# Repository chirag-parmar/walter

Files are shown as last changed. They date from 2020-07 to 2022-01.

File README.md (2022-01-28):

# Walter: The Water Butler

> Proof of concept document can be found [here](docs/POC.md)

### Dependencies: *(Tested on MACOS)*

1. [Download](https://www.nordicsemi.com/Software-and-tools/Software/nRF5-SDK/Download) nRF5 SDK
2. [Download](https://developer.arm.com/tools-and-software/open-source-software/developer-tools/gnu-toolchain/gnu-rm/downloads) ARM GCC toolchain
4. [Download](https://www.nordicsemi.com/Software-and-Tools/Development-Tools/nRF-Command-Line-Tools/Download#infotabs) nRF5x Command Line Tools.
4. Extract nRF5 SDK and rename the extracted folder to `nrf5-sdk`.
5. Extract GCC ARM toolchain and rename the extracted folder to `arm-toolchain`
6. Extract `nRF5x Command Line Tools` TAR file.
    * Navigate inside the nrf ommand line tools folder and install the Jlink package withing it.
    * Navigate inside the nrf ommand line tools folder and install the `nRF5x Command Line Tools` package withing it.
7. Check installations
    * J-Link *(MAC-OS)*: Check if this path exists `/Applications/SEGGER/JLink`
    * nRF5x Command Line Tools: `nrfjprog -v` must output the version.
8. Export Environment variables to specifying SDK folder path and ARM toolchain path.
    * `export SDK_ROOT=<PATH TO nrf5-sdk/ folder>`
    * `export GNU_INSTALL_ROOT=<PATH TO arm-toolchain/bin/ folder>`

> MAC-OS Complications: The system is going to complain that "the developer cannot be verified" for `arm-none-eabi-gcc`, `cc1`, `as`, `collect2`, `ld`, `liblto_plugin.0.so`, `arm-none-eabi-size`, `arm-none-eabi-objcopy`. Click on `Cancel` and then open Security and Privacy settings and click on `Allow Anyway`. These complains are gonna show one after the another.

### Burning the software:
```bash
make flash
```

### TODO:
* [x] [IMPORTANT] Debug NRF52840 - doesn't stop advertising at all
* [x] [IMPORTANT] initialize GPIO only while reading the sensor.
* [x] [IMPORTANT] Debug app: after refresh or after close and restart of app BLE shows connected but not re4ading notifications - most probably it is the BleManager object that has gone out of scope.
* [ ] README Documentation
  * [ ] NRF softdevice and flashing instructions without debugger and with debugger 
* [ ] Statistical and Analytical
  * [ ] function for analysing a day's worth of data and extracting the num. of bottles drank metric
  * [ ] triggers for interacting with the user
  * [ ] Touch sensing
* [ ] Software
  * [ ] Using NRF52840 Dongle.
    * [x] Port Capcitive Sensor library to nRF
    * [x] Define BLE services and characteristics
    * [ ] Finish battery level indication integration (depends on power supply design)
  * [x] App Design
    * [x] POC integration with BLE
    * [x] UI Wire Frame
    * [x] UI Design and Integration with BLE
    * [x] run ble recorded in background
    * [x] save data locally - ~~use firebase~~
      * [x] save device info
      * [x] save readings
      * [x] save calibration values
      * [x] save settings
      * [x] save on change
    * [x] Main screen statistics design
* [ ] Hardware
  * [ ] Sensor fabrication documentation
  * [ ] hardware fabrication documentation
  * [x] ~~Aluminium or Copper Tape electrodes~~ - didn't try but shouldn't be too different
  * [x] ~~3D printed case~~ - Going with no case design. who cares about the case anyway. The board is waterproofed
  * [x] Power supply design
    * [x] Coin Cells/ Super Capacitors - Super capacitor can power only for 6 minutes
      * [x] Investigate if we can use coin cells/super capacitors
      * [x] Calculate the usage time per charge and choose an appropriately sized battery
      * [x] Design necessary circuitry for using coin/cell or supercapcitors
      * [x] Fabricate and Integrate circuitry and battery with nrf52840

### Power Caclulations for Supercapacitor

Current draw - 11uA for 8 s and 3 ma for 2s => ~600uA (average)
Power Consumption at 3.6v = 3.6v * 600uA => 2.16mW

Energy stored in the capacitor = 1/2*C*deltaV*deltaV = 0.5 * 1F * (3.6v- 2v)^2 = 1.28J Joules

Energy = Power * Time => Time = Energy/Power => 1.28J/2.16mW => 592s => ~10minutes

**Decision:** Use CR2032 or better rechargeable CR2032

### Future Ideas:

* [ ] onboarding flow
* [ ] social - share water usage statistics with a friend, challenges etc.
* [ ] better UI

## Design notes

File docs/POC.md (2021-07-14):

# Walter: Proof of Concept

> The proof of concept is done using arduino uno. The .ino files can be found in the `arduino` folder.

## The Science of Walter

The primary design goal of this project is to use a non-intrusive sensor to avoid contamination of potable water. Therefore, we use a DIY capacitance based sensor and to keep it simple we go with parallel plate design. The two plates are made of aluminium foil and are fixed to the outside wall of the bottle. To create a mathematical model let's start with the famous capacitance equation shown below.

parallel_plate_cap

Since the combined dielectric constant would be a function of the height of the water we can simply measure the capacitance and deduce the height of the water. Easy-peazy lemon-squeazy, just that it is not that easy.

The first complexity is that we cannot model it as a parallel plate capacitor. Simply because the plates are not parallel, in other words, the distance between the plates is not constant it varies along the shorter edge of the plate.

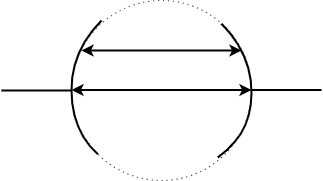
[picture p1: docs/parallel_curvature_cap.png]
parallel_curvature_cap


The second complexity is that the electrical conductivity of water also has a role to play in the increase of capacitance. Potable water even though being "bad" is a conductor (unless you are drinking distilled water). Due to this the water acts like a "bad" conducting metal slab between our capacitor. Due to this the effective capacitor circuit is equivalent to two capacitors connected in series with a high reistance between them. Watch [this](https://www.youtube.com/watch?v=ygADYZEBmtc) video to know why.

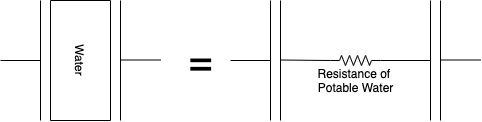
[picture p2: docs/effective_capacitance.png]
effective_capacitance


Therefore, in addition to factoring in a "varying" `d` we would also have to factor in the effect of water as a bad conductor(the electrical conductivity) along with the effect of dielectric constant. One cannot get tangled into the physics of things while playing the role of a hobbyist (one can actually, but one is planning not to. XD). So we just move forward by considering it to be a blackbox and use analytical methods to find the relation between the capacitance and the level of water.

## The Analytics of Walter

#### Quick Setup:
```bash
virtualenv venv
source venv/bin/activate
pip3 install -r requirements.txt
```

#### Collecting Datapoints:

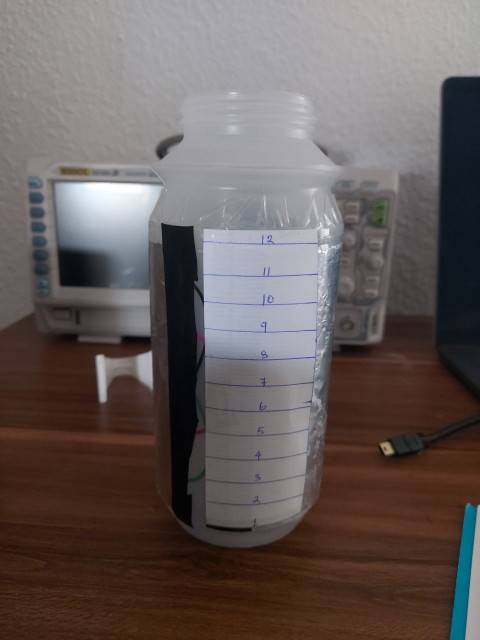
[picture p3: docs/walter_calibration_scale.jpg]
walter_calibration_scale


```bash
python3 scripts/create_dataset.py
```

This python script runs a infinite loop while asking the user two questions in every iteration fo the loop.

1. "Enter number of datapoints to collect(q/Q - quit): " - this is where the user can specify the number of datapoints to be collected or type in `q` or `Q` to quit.
2. "Enter the level of water: " - The water level entered here will be used for all the datapoints that were specified in the question above.

Each datapoint is stored as JSON string as shown below and each dataset is a `List` of datapoints.

```json
{
  "index": 0,
  "val": 742,
  "level": 0,
}
```

* `index` (*self-explanatory*)automatically incremented for every new datapoint.
* `val` represents the sensor value.
* `level` marks the level of water.

This repository has two pre-existing datasets,
1. `linear_filling` - datapoints are collected starting from `level 0` and linearly incrementing thereafter upto `level 13`.
2. `exponential_filling` datapoints are collected starting from `level 0` and exponentially incrementing thereafter upto level 13 i.e. at 0, 1, 2, 4, 8, 13

#### Analyzing the data:

```bash
python3 scripts/statistics.py datasets/<name_of_json_dataset>
```

Linear Filling:
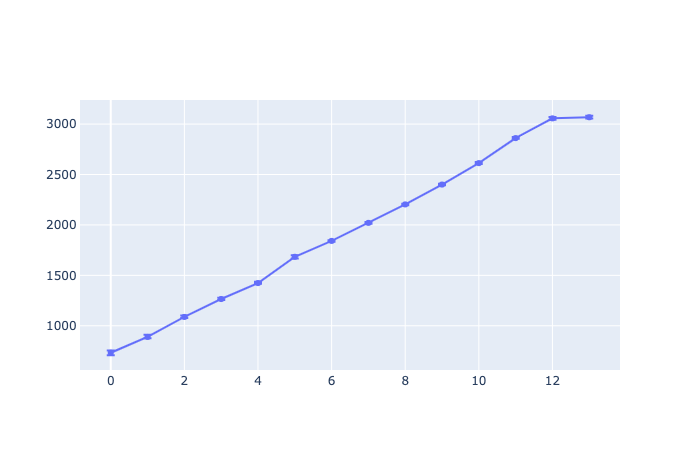
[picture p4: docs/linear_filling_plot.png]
linear_filling_plot

*zoomed in view of `level 6` error bar*
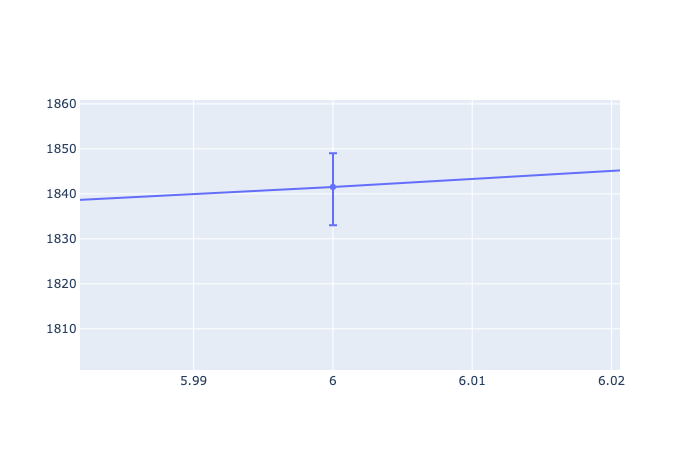
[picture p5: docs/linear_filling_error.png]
linear_filling_error


Exponential Filling:
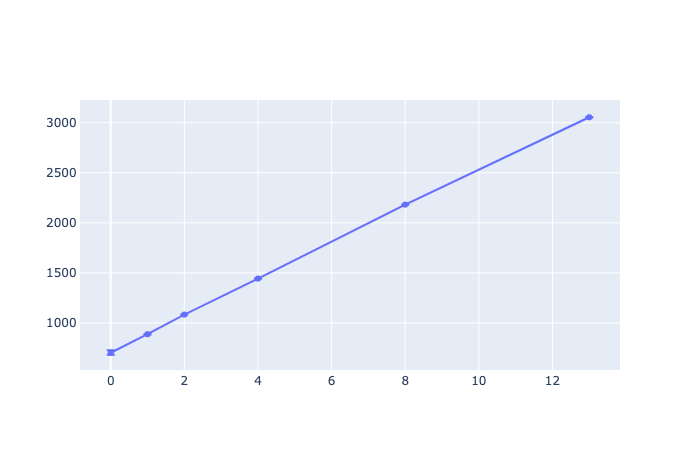
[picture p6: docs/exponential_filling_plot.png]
exponential_filling_plot

*zoomed in view of `level 4` error bar*
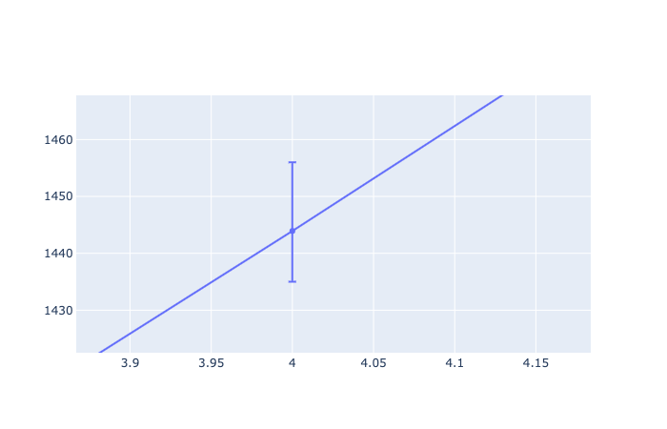
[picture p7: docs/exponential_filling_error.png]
exponential_filling_error


We can deduce the following conclusions of the experiment
1. The sensor value is more or less **linearly** dependent on the level of water.
    * Flattening/breaking of the line after `level 12` of water in the `linear_filling` plot is because level 13 is above the plate area of the capacitor and hence has no or minimal effect on the capacitance.
2. The error in the values is max at +/- 10. This is **super awesome** considering we had to write only a couple of lines of code and solder one resistor to make the sensor.

Further questions to ponder upon:
* Is the linear relationship because of the **uniform** nature of the cylindrical bottle?
* What if the shape of the bottle is not uniform across the cross section of the plates
* Since the relationship is linear can we simply collect two datapoints and compute the line equation? (reaping the benefits of continuity of the realtionship)

## The Touch of Walter

The touch sensing of Walter was an accidental discovery but was not surprising because we are using `CapacitiveSensor` library. This library is majorly used for capacitive `touch` sensing.

So when we open up a up the `serial plotter` provided inside the Arduino IDE and connect Walter via a serial connection we notice that:
1. The sensor value shoots up higher than normal when we touch the bottle.
2. The touch values are higher when the bottle is grabbed tighter.
3. The touch values are higher when the bottle is filled up.

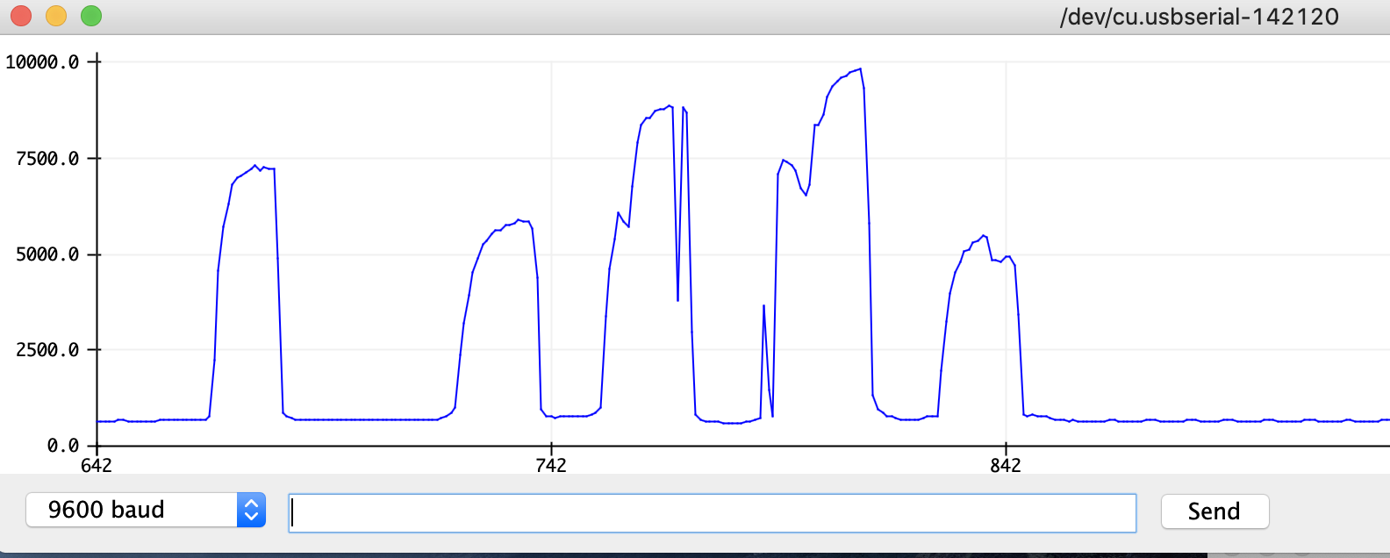
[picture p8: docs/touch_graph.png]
touch_graph


Since the sensor values are *wayyyyyy* higher than normal values we can check for threshold. Whenever the sensor value is greater than this threshold then we can say that the bottle is touched.

For the above graph a practical threshold value would be `5000` since all the peaks cross that mark and our normal maximum value is close to `3000`(full bottle)

#### Circuit Diagram:
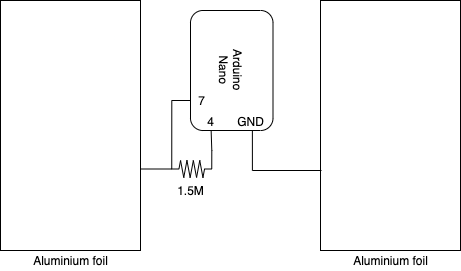
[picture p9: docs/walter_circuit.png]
walter_circuit


## Images
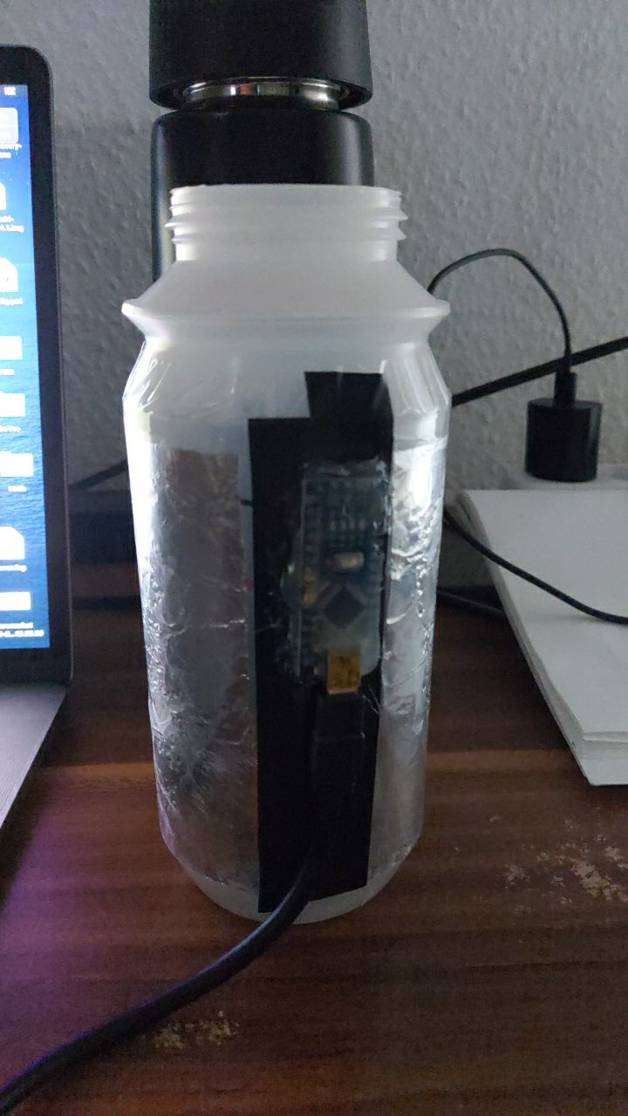
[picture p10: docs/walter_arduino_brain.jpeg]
walter_arduino_brain


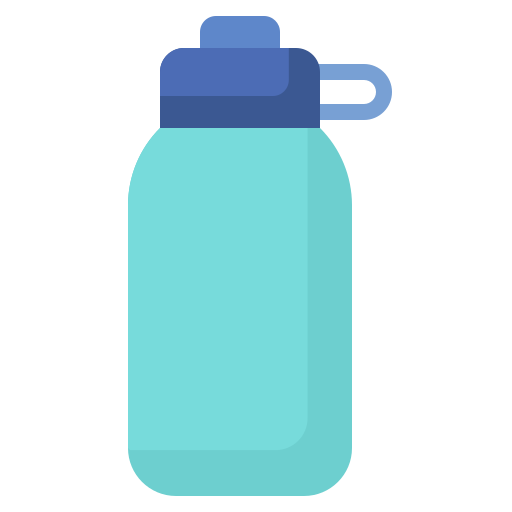
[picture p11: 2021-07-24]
app/Walter/src/resources/water-bottle-blue.png

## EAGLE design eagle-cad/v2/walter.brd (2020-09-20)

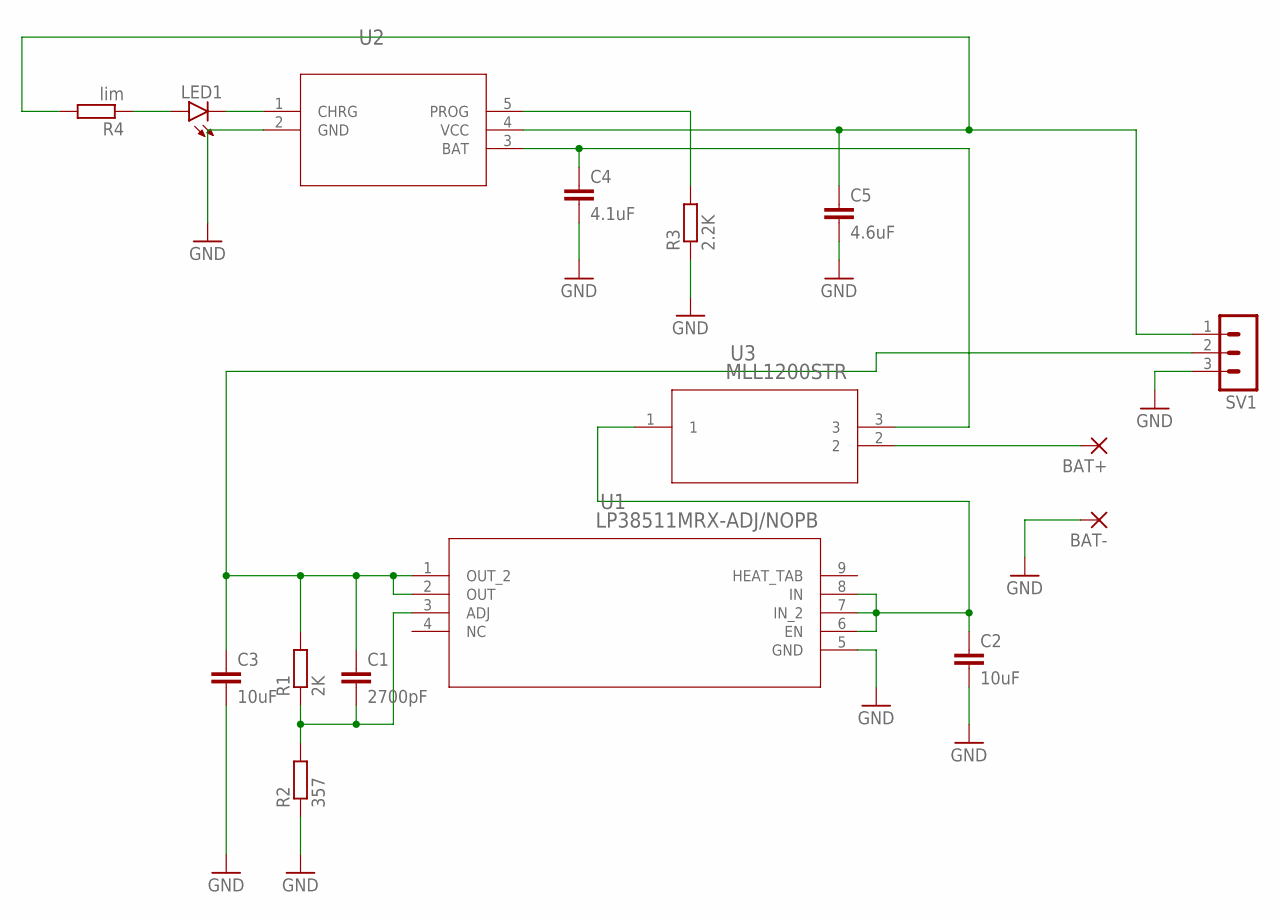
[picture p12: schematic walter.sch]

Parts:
BAT+: 1,6/0,8
BAT-: 1,6/0,8
C1: 2700pF; C0402
C2, C3: 10uF; C0603
C4: 4.1uF; C0603
C5: 4.6uF; C0603
LED1: LEDCHIP-LED0603; CHIP-LED0603
R1: 2K; R0402
R2: 357; R0603
R3: 2.2K; R0603
R4: lim; R0402
SV1: MA03-1
U1: LP38511MRX-ADJ/NOPB; MRA08B_TEX
U2: LTC4054LES5-4.2TRPBF; S_5_ADI
U3: MLL1200STR; SW_MLL1200STR_TEC

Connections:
GND: BAT-.1, C2.2, C3.2, C4.2, C5.2, R2.1, R3.1, SV1.3, U1.5 (GND), U2.2 (GND)
unnamed: C2.1, U1.6 (EN), U1.7 (IN_2), U1.8 (IN), U3.1
unnamed: C4.1, U2.3 (BAT), U3.3
unnamed: C1.1, C3.1, R1.2, SV1.2, U1.1 (OUT_2), U1.2 (OUT)
unnamed: C1.2, R1.1, R2.2, U1.3 (ADJ)
unnamed: BAT+.1, U3.2
unnamed: R3.2, U2.5 (PROG)
unnamed: C5.1, R4.2, SV1.1, U2.4 (VCC)
unnamed: LED1.A, R4.1
unnamed: LED1.C, U2.1 (CHRG)

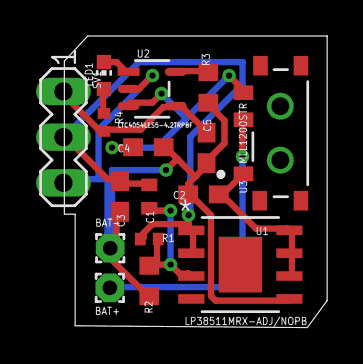
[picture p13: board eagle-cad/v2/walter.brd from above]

Board: 2 copper layers, 14.6 x 16.2 mm, 16 parts (0 on the bottom side), 10 nets.

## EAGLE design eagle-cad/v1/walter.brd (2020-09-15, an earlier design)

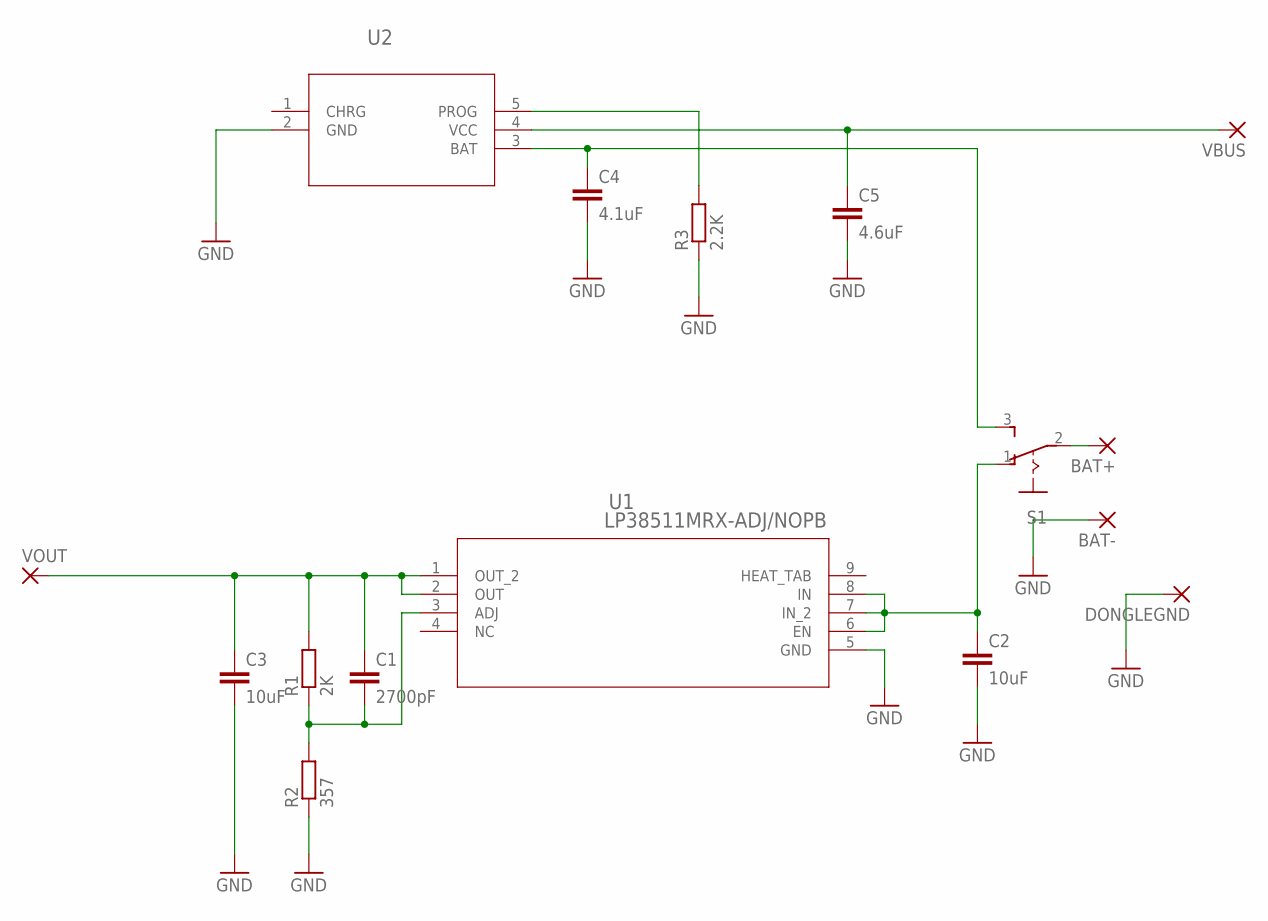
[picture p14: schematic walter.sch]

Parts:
BAT+: 1,6/0,8
BAT-: 1,6/0,8
C1: 2700pF; C0402
C2, C3: 10uF; C0603
C4: 4.1uF; C0603
C5: 4.6uF; C0603
DONGLEGND: 1,6/0,8
R1: 2K; R0402
R2: 357; R0603
R3: 2.2K; R0603
S1: 255SB
U1: LP38511MRX-ADJ/NOPB; MRA08B_TEX
U2: LTC4054LES5-4.2TRPBF; S_5_ADI
VBUS: 1,6/0,8
VOUT: 1,6/0,8

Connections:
GND: BAT-.1, C2.2, C3.2, C4.2, C5.2, DONGLEGND.1, R2.1, R3.1, U1.5 (GND), U2.2 (GND)
unnamed: C2.1, S1.1 (O), U1.6 (EN), U1.7 (IN_2), U1.8 (IN)
unnamed: C4.1, S1.3 (S), U2.3 (BAT)
unnamed: C1.1, C3.1, R1.2, U1.1 (OUT_2), U1.2 (OUT), VOUT.1
unnamed: C1.2, R1.1, R2.2, U1.3 (ADJ)
unnamed: BAT+.1, S1.2
unnamed: R3.2, U2.5 (PROG)
unnamed: C5.1, U2.4 (VCC), VBUS.1

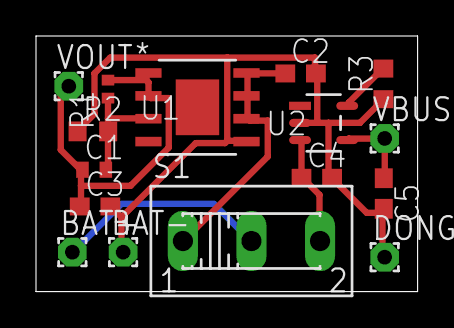
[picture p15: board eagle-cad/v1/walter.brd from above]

Board: 2 copper layers, 21.2 x 14.2 mm, 16 parts (0 on the bottom side), 8 nets.

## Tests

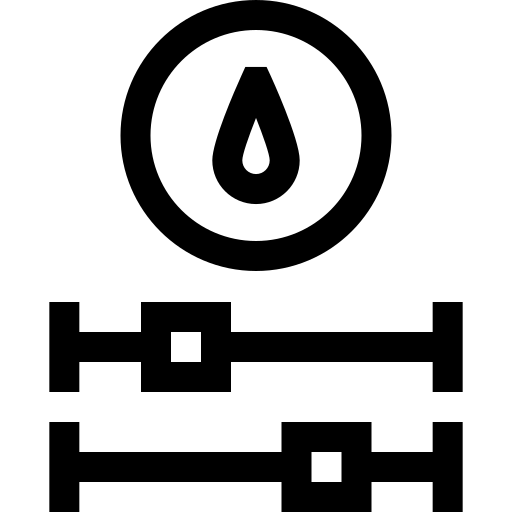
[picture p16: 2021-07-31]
app/Walter/src/resources/calibrate.png

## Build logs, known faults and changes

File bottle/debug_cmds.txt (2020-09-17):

target remote localhost:2331
mon speed 10000
mon flash download=1
load
break main
mon reset 0

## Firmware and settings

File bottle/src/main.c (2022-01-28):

/* Standard Includes */
#include <stdbool.h>
#include <stdint.h>
#include <string.h>

/* SDK Includes */
#include "nordic_common.h"
#include "nrf.h"
#include "app_error.h"
#include "ble.h"
#include "ble_hci.h"
#include "ble_srv_common.h"
#include "ble_advdata.h"
#include "ble_advertising.h"
#include "ble_conn_params.h"
#include "nrf_sdh.h"
#include "nrf_sdh_soc.h"
#include "nrf_sdh_ble.h"
#include "app_timer.h"
#include "fds.h"
#include "peer_manager.h"
#include "peer_manager_handler.h"
#include "bsp_btn_ble.h"
#include "sensorsim.h"
#include "ble_conn_state.h"
#include "nrf_ble_gatt.h"
#include "nrf_ble_lesc.h"
#include "nrf_ble_qwr.h"
#include "nrf_pwr_mgmt.h"
#include "nrf_log.h"
#include "nrf_log_ctrl.h"
#include "nrf_log_default_backends.h"

/* Project Includes */
#include "ble_walter.h"
#include "wlm_sensor.h"

#define DEVICE_NAME                     "Walter"                                /**< Name of device. Will be included in the advertising data. */
#define MANUFACTURER_NAME               "Parmar Industries"                     /**< Manufacturer. Will be passed to Device Information Service. */
#define APP_ADV_INTERVAL                300                                     /**< The advertising interval (in units of 0.625 ms. This value corresponds to 187.5 ms). */

#define APP_ADV_DURATION                3000                                    /**< The advertising duration (180 seconds) in units of 10 milliseconds. */
#define APP_BLE_OBSERVER_PRIO           3                                       /**< Application's BLE observer priority. You shouldn't need to modify this value. */
#define APP_BLE_CONN_CFG_TAG            1                                       /**< A tag identifying the SoftDevice BLE configuration. */

#define MIN_CONN_INTERVAL               MSEC_TO_UNITS(1000, UNIT_1_25_MS)        /**< Minimum acceptable connection interval (4 seconds). */
#define MAX_CONN_INTERVAL               MSEC_TO_UNITS(1000, UNIT_1_25_MS)        /**< Maximum acceptable connection interval (4 second). */
#define SLAVE_LATENCY                   10                                      /**< Slave latency. */
#define CONN_SUP_TIMEOUT                MSEC_TO_UNITS(30000, UNIT_10_MS)         /**< Connection supervisory timeout (4 seconds). */

#define FIRST_CONN_PARAMS_UPDATE_DELAY  APP_TIMER_TICKS(5000)                   /**< Time from initiating event (connect or start of notification) to first time sd_ble_gap_conn_param_update is called (5 seconds). */
#define NEXT_CONN_PARAMS_UPDATE_DELAY   APP_TIMER_TICKS(5000)                  /**< Time between each call to sd_ble_gap_conn_param_update after the first call (30 seconds). */
#define MAX_CONN_PARAMS_UPDATE_COUNT    3                                       /**< Number of attempts before giving up the connection parameter negotiation. */

#define SEC_PARAM_BOND                  1                                       /**< Perform bonding. */
#define SEC_PARAM_MITM                  0                                       /**< Man In The Middle protection not required. */
#define SEC_PARAM_LESC                  0                                       /**< LE Secure Connections not enabled. */
#define SEC_PARAM_KEYPRESS              0                                       /**< Keypress notifications not enabled. */
#define SEC_PARAM_IO_CAPABILITIES       BLE_GAP_IO_CAPS_NONE                    /**< No I/O capabilities. */
#define SEC_PARAM_OOB                   0                                       /**< Out Of Band data not available. */
#define SEC_PARAM_MIN_KEY_SIZE          7                                       /**< Minimum encryption key size. */
#define SEC_PARAM_MAX_KEY_SIZE          16                                      /**< Maximum encryption key size. */

#define DEAD_BEEF                       0xDEADBEEF                              /**< Value used as error code on stack dump, can be used to identify stack location on stack unwind. */

// #define BATTERY_TIMER_INTERVAL          APP_TIMER_TICKS(1000)                   // 1000 ms intervals
#define WLM_TIMER_INTERVAL              APP_TIMER_TICKS(30000)                   // 5 min intervals

//POWER configuration
#define TX_POWER_CONN                   -16
#define TX_POWER_ADV                    -16

NRF_BLE_GATT_DEF(m_gatt);                                                       /**< GATT module instance. */
NRF_BLE_QWR_DEF(m_qwr);                                                         /**< Context for the Queued Write module.*/
BLE_ADVERTISING_DEF(m_advertising);                                             /**< Advertising module instance. */
// APP_TIMER_DEF(m_battery_timer_id);                                              /**< Battery timer. */
APP_TIMER_DEF(m_wlm_timer_id);                                                  /**< water level measurement timer. */

static uint16_t m_conn_handle = BLE_CONN_HANDLE_INVALID;                        /**< Handle of the current connection. */

BLE_WALTER_SERVICE_DEF(m_walter_service);

static ble_uuid_t m_adv_uuids[] =                                               /**< Universally unique service identifiers. */
{
    {WALTER_SERVICE_UUID, BLE_UUID_TYPE_VENDOR_BEGIN}
};


static void advertising_start(bool erase_bonds);


/**@brief Callback function for asserts in the SoftDevice.
 *
 * @details This function will be called in case of an assert in the SoftDevice.
 *
 * @warning This handler is an example only and does not fit a final product. You need to analyze
 *          how your product is supposed to react in case of Assert.
 * @warning On assert from the SoftDevice, the system can only recover on reset.
 *
 * @param[in] line_num   Line number of the failing ASSERT call.
 * @param[in] file_name  File name of the failing ASSERT call.
 */
void assert_nrf_callback(uint16_t line_num, const uint8_t * p_file_name)
{
    app_error_handler(DEAD_BEEF, line_num, p_file_name);
}


/**@brief Function for handling Peer Manager events.
 *
 * @param[in] p_evt  Peer Manager event.
 */
static void pm_evt_handler(pm_evt_t const * p_evt)
{
    pm_handler_on_pm_evt(p_evt);
    pm_handler_flash_clean(p_evt);

    switch (p_evt->evt_id)
    {
        case PM_EVT_PEERS_DELETE_SUCCEEDED:
            advertising_start(false);
            break;

        default:
            break;
    }
}

static void timers_start() {
    ret_code_t err_code;
    err_code = app_timer_start(m_wlm_timer_id, WLM_TIMER_INTERVAL, NULL);
    APP_ERROR_CHECK(err_code);

    // err_code = app_timer_start(m_battery_timer_id, BATTERY_TIMER_INTERVAL, NULL);
    // APP_ERROR_CHECK(err_code);
}

// static void timers_stop() {
//     ret_code_t err_code;
//     err_code = app_timer_stop(m_wlm_timer_id);
//     APP_ERROR_CHECK(err_code);

//     // err_code = app_timer_stop(m_battery_timer_id);
//     // APP_ERROR_CHECK(err_code);
// }

static uint32_t water_level = 0UL;
static void wlm_timer_timeout_handler(void * p_context) {

    ret_code_t err_code;

    //intialize the sensor
    wlm_sensor_init();
    water_level = wlm_sensor_get_reading();
    wlm_sensor_uninit();
    err_code = water_level_update(&m_walter_service, &water_level);

    if ((err_code != NRF_SUCCESS) &&
        (err_code != NRF_ERROR_INVALID_STATE) &&
        (err_code != NRF_ERROR_RESOURCES) &&
        (err_code != NRF_ERROR_BUSY) &&
        (err_code != BLE_ERROR_GATTS_SYS_ATTR_MISSING)
       )
    {
        APP_ERROR_HANDLER(err_code);
    }
}

static void timers_init(void)
{
    // Initialize timer module.
    ret_code_t err_code = app_timer_init();
    APP_ERROR_CHECK(err_code);

    // Create timers.

    err_code = app_timer_create(&m_wlm_timer_id, APP_TIMER_MODE_REPEATED, wlm_timer_timeout_handler);
    APP_ERROR_CHECK(err_code);

    // err_code = app_timer_create(&m_battery_timer_id, APP_TIMER_MODE_REPEATED, battery_timer_timeout_handler);
    // APP_ERROR_CHECK(err_code); */
}


/**@brief Function for the GAP initialization.
 *
 * @details This function sets up all the necessary GAP (Generic Access Profile) parameters of the
 *          device including the device name, appearance, and the preferred connection parameters.
 */
static void gap_params_init(void)
{
    ret_code_t              err_code;
    ble_gap_conn_params_t   gap_conn_params;
    ble_gap_conn_sec_mode_t sec_mode;

    BLE_GAP_CONN_SEC_MODE_SET_OPEN(&sec_mode);

    err_code = sd_ble_gap_device_name_set(&sec_mode,
                                          (const uint8_t *)DEVICE_NAME,
                                          strlen(DEVICE_NAME));
    APP_ERROR_CHECK(err_code);

    err_code = sd_ble_gap_appearance_set(BLE_APPEARANCE_GENERIC_OUTDOOR_SPORTS_ACT);
    APP_ERROR_CHECK(err_code);

    memset(&gap_conn_params, 0, sizeof(gap_conn_params));

    gap_conn_params.min_conn_interval = MIN_CONN_INTERVAL;
    gap_conn_params.max_conn_interval = MAX_CONN_INTERVAL;
    gap_conn_params.slave_latency     = SLAVE_LATENCY;
    gap_conn_params.conn_sup_timeout  = CONN_SUP_TIMEOUT;

    err_code = sd_ble_gap_ppcp_set(&gap_conn_params);
    APP_ERROR_CHECK(err_code);
}


/**@brief Function for initializing the GATT module.
 */
static void gatt_init(void)
{
    ret_code_t err_code = nrf_ble_gatt_init(&m_gatt, NULL);
    APP_ERROR_CHECK(err_code);
}


/**@brief Function for handling Queued Write Module errors.
 *
 * @details A pointer to this function will be passed to each service which may need to inform the
 *          application about an error.
 *
 * @param[in]   nrf_error   Error code containing information about what went wrong.
 */
static void nrf_qwr_error_handler(uint32_t nrf_error)
{
    APP_ERROR_HANDLER(nrf_error);
}

/**@brief Function for initializing services that will be used by the application.
 */
static void services_init(void)
{
    ret_code_t         err_code;
    nrf_ble_qwr_init_t qwr_init = {0};

    // Initialize Queued Write Module.
    qwr_init.error_handler = nrf_qwr_error_handler;

    err_code = nrf_ble_qwr_init(&m_qwr, &qwr_init);
    APP_ERROR_CHECK(err_code);

    err_code = ble_walter_service_init(&m_walter_service);
    APP_ERROR_CHECK(err_code);
}


/**@brief Function for handling the Connection Parameters Module.
 *
 * @details This function will be called for all events in the Connection Parameters Module which
 *          are passed to the application.
 *          @note All this function does is to disconnect. This could have been done by simply
 *                setting the disconnect_on_fail config parameter, but instead we use the event
 *                handler mechanism to demonstrate its use.
 *
 * @param[in] p_evt  Event received from the Connection Parameters Module.
 */
static void on_conn_params_evt(ble_conn_params_evt_t * p_evt)
{
    ret_code_t err_code;

    if (p_evt->evt_type == BLE_CONN_PARAMS_EVT_FAILED)
    {
        err_code = sd_ble_gap_disconnect(m_conn_handle, BLE_HCI_CONN_INTERVAL_UNACCEPTABLE);
        APP_ERROR_CHECK(err_code);
    }
}


/**@brief Function for handling a Connection Parameters error.
 *
 * @param[in] nrf_error  Error code containing information about what went wrong.
 */
static void conn_params_error_handler(uint32_t nrf_error)
{
    APP_ERROR_HANDLER(nrf_error);
}


/**@brief Function for initializing the Connection Parameters module.
 */
static void conn_params_init(void)
{
    ret_code_t             err_code;
    ble_conn_params_init_t cp_init;

    memset(&cp_init, 0, sizeof(cp_init));

    cp_init.p_conn_params                  = NULL;
    cp_init.first_conn_params_update_delay = FIRST_CONN_PARAMS_UPDATE_DELAY;
    cp_init.next_conn_params_update_delay  = NEXT_CONN_PARAMS_UPDATE_DELAY;
    cp_init.max_conn_params_update_count   = MAX_CONN_PARAMS_UPDATE_COUNT;
    cp_init.start_on_notify_cccd_handle    = BLE_GATT_HANDLE_INVALID;
    cp_init.disconnect_on_fail             = false;
    cp_init.evt_handler                    = on_conn_params_evt;
    cp_init.error_handler                  = conn_params_error_handler;

    err_code = ble_conn_params_init(&cp_init);
    APP_ERROR_CHECK(err_code);
}

/**@brief Function for putting the chip into sleep mode.
 *
 * @note This function will not return.
 */
static void sleep_mode_enter(void)
{
    ret_code_t err_code;

    err_code = bsp_indication_set(BSP_INDICATE_IDLE);
    APP_ERROR_CHECK(err_code);

    // Prepare wakeup buttons.
    err_code = bsp_btn_ble_sleep_mode_prepare();
    APP_ERROR_CHECK(err_code);

    // Go to system-off mode (this function will not return; wakeup will cause a reset).
    err_code = sd_power_system_off();
    APP_ERROR_CHECK(err_code);
}


/**@brief Function for handling advertising events.
 *
 * @details This function will be called for advertising events which are passed to the application.
 *
 * @param[in] ble_adv_evt  Advertising event.
 */
static void on_adv_evt(ble_adv_evt_t ble_adv_evt)
{
    ret_code_t err_code;

    switch (ble_adv_evt)
    {
        case BLE_ADV_EVT_FAST:
            NRF_LOG_INFO("Fast advertising.");
            err_code = bsp_indication_set(BSP_INDICATE_ADVERTISING);
            APP_ERROR_CHECK(err_code);
            break;

        case BLE_ADV_EVT_IDLE:
            sleep_mode_enter();
            break;

        default:
            break;
    }
}

/**@brief Function for changing the tx power.
 */
static void adv_tx_power_set()
{
    ret_code_t err_code = sd_ble_gap_tx_power_set(BLE_GAP_TX_POWER_ROLE_ADV, m_advertising.adv_handle, TX_POWER_ADV);
    APP_ERROR_CHECK(err_code);
}

/**@brief Function for changing the tx power.
 */
static void conn_tx_power_set()
{
    ret_code_t err_code = sd_ble_gap_tx_power_set(BLE_GAP_TX_POWER_ROLE_CONN, m_conn_handle, TX_POWER_CONN);
    APP_ERROR_CHECK(err_code);
}


/**@brief Function for handling BLE events.
 *
 * @param[in]   p_ble_evt   Bluetooth stack event.
 * @param[in]   p_context   Unused.
 */
static void ble_evt_handler(ble_evt_t const * p_ble_evt, void * p_context)
{
    ret_code_t err_code = NRF_SUCCESS;

    switch (p_ble_evt->header.evt_id)
    {
        case BLE_GAP_EVT_DISCONNECTED:
            NRF_LOG_INFO("Disconnected.");
            // LED indication will be changed when advertising starts.
            break;

        case BLE_GAP_EVT_CONNECTED:
            NRF_LOG_INFO("Connected.");
            err_code = bsp_indication_set(BSP_INDICATE_USER_STATE_OFF);
            APP_ERROR_CHECK(err_code);
            m_conn_handle = p_ble_evt->evt.gap_evt.conn_handle;
            err_code = nrf_ble_qwr_conn_handle_assign(&m_qwr, m_conn_handle);
            APP_ERROR_CHECK(err_code);
            conn_tx_power_set();
            break;

        case BLE_GAP_EVT_PHY_UPDATE_REQUEST:
        {
            NRF_LOG_DEBUG("PHY update request.");
            ble_gap_phys_t const phys =
            {
                .rx_phys = BLE_GAP_PHY_AUTO,
                .tx_phys = BLE_GAP_PHY_AUTO,
            };
            err_code = sd_ble_gap_phy_update(p_ble_evt->evt.gap_evt.conn_handle, &phys);
            APP_ERROR_CHECK(err_code);
        } break;

        case BLE_GATTC_EVT_TIMEOUT:
            // Disconnect on GATT Client timeout event.
            NRF_LOG_DEBUG("GATT Client Timeout.");
            err_code = sd_ble_gap_disconnect(p_ble_evt->evt.gattc_evt.conn_handle,
                                             BLE_HCI_REMOTE_USER_TERMINATED_CONNECTION);
            APP_ERROR_CHECK(err_code);
            break;

        case BLE_GATTS_EVT_TIMEOUT:
            // Disconnect on GATT Server timeout event.
            NRF_LOG_DEBUG("GATT Server Timeout.");
            err_code = sd_ble_gap_disconnect(p_ble_evt->evt.gatts_evt.conn_handle,
                                             BLE_HCI_REMOTE_USER_TERMINATED_CONNECTION);
            APP_ERROR_CHECK(err_code);
            break;

        // case BLE_GATTS_EVT_WRITE:
        //     if (p_ble_evt->evt.gatts_evt.params.write.handle == m_walter_service.wlm_handles.cccd_handle &&
        //         p_ble_evt->evt.gatts_evt.params.write.data[0] == 0x01) {
        //             timers_start();
        //     } else if (p_ble_evt->evt.gatts_evt.params.write.handle == m_walter_service.wlm_handles.cccd_handle &&
        //                p_ble_evt->evt.gatts_evt.params.write.data[0] != 0x01) {
        //             timers_stop();
        //     }
        //     break;

        default:
            // No implementation needed.
            break;
    }
}


/**@brief Function for initializing the BLE stack.
 *
 * @details Initializes the SoftDevice and the BLE event interrupt.
 */
static void ble_stack_init(void)
{
    ret_code_t err_code;

    err_code = nrf_sdh_enable_request();
    APP_ERROR_CHECK(err_code);

    // Configure the BLE stack using the default settings.
    // Fetch the start address of the application RAM.
    uint32_t ram_start = 0;
    err_code = nrf_sdh_ble_default_cfg_set(APP_BLE_CONN_CFG_TAG, &ram_start);
    APP_ERROR_CHECK(err_code);

    // Enable BLE stack.
    err_code = nrf_sdh_ble_enable(&ram_start);
    APP_ERROR_CHECK(err_code);

    // Register a handler for BLE events.
    NRF_SDH_BLE_OBSERVER(m_ble_observer, APP_BLE_OBSERVER_PRIO, ble_evt_handler, NULL);

    NRF_SDH_BLE_OBSERVER(m_walter_service_observer, 
                         APP_BLE_OBSERVER_PRIO, 
                         ble_walter_service_on_ble_evt, 
                         (void*) &m_walter_service);
}


/**@brief Function for the Peer Manager initialization.
 */
static void peer_manager_init(void)
{
    ble_gap_sec_params_t sec_param;
    ret_code_t           err_code;

    err_code = pm_init();
    APP_ERROR_CHECK(err_code);

    memset(&sec_param, 0, sizeof(ble_gap_sec_params_t));

    // Security parameters to be used for all security procedures.
    sec_param.bond           = SEC_PARAM_BOND;
    sec_param.mitm           = SEC_PARAM_MITM;
    sec_param.lesc           = SEC_PARAM_LESC;
    sec_param.keypress       = SEC_PARAM_KEYPRESS;
    sec_param.io_caps        = SEC_PARAM_IO_CAPABILITIES;
    sec_param.oob            = SEC_PARAM_OOB;
    sec_param.min_key_size   = SEC_PARAM_MIN_KEY_SIZE;
    sec_param.max_key_size   = SEC_PARAM_MAX_KEY_SIZE;
    sec_param.kdist_own.enc  = 1;
    sec_param.kdist_own.id   = 1;
    sec_param.kdist_peer.enc = 1;
    sec_param.kdist_peer.id  = 1;

    err_code = pm_sec_params_set(&sec_param);
    APP_ERROR_CHECK(err_code);

    err_code = pm_register(pm_evt_handler);
    APP_ERROR_CHECK(err_code);
}


/**@brief Clear bond information from persistent storage.
 */
static void delete_bonds(void)
{
    ret_code_t err_code;

    NRF_LOG_INFO("Erase bonds!");

    err_code = pm_peers_delete();
    APP_ERROR_CHECK(err_code);
}


/**@brief Function for handling events from the BSP module.
 *
 * @param[in]   event   Event generated when button is pressed.
 */
static void bsp_event_handler(bsp_event_t event)
{
    ret_code_t err_code;

    switch (event)
    {
        case BSP_EVENT_SLEEP:
            sleep_mode_enter();
            break; // BSP_EVENT_SLEEP

        case BSP_EVENT_DISCONNECT:
            err_code = sd_ble_gap_disconnect(m_conn_handle,
                                             BLE_HCI_REMOTE_USER_TERMINATED_CONNECTION);
            if (err_code != NRF_ERROR_INVALID_STATE)
            {
                APP_ERROR_CHECK(err_code);
            }
            break; // BSP_EVENT_DISCONNECT

        case BSP_EVENT_WHITELIST_OFF:
            if (m_conn_handle == BLE_CONN_HANDLE_INVALID)
            {
                err_code = ble_advertising_restart_without_whitelist(&m_advertising);
                if (err_code != NRF_ERROR_INVALID_STATE)
                {
                    APP_ERROR_CHECK(err_code);
                }
            }
            break; // BSP_EVENT_KEY_0

        default:
            break;
    }
}


/**@brief Function for initializing the Advertising functionality.
 */
static void advertising_init(void)
{
    ret_code_t             err_code;
    ble_advertising_init_t init;

    memset(&init, 0, sizeof(init));

    init.advdata.name_type               = BLE_ADVDATA_FULL_NAME;
    init.advdata.include_appearance      = true;
    init.advdata.flags                   = BLE_GAP_ADV_FLAGS_LE_ONLY_GENERAL_DISC_MODE;

    //Send service uuid information in scan response instead of main advertising packet
    init.srdata.uuids_complete.uuid_cnt = sizeof(m_adv_uuids) / sizeof(m_adv_uuids[0]);
    init.srdata.uuids_complete.p_uuids  = m_adv_uuids;

    init.config.ble_adv_fast_enabled  = true;
    init.config.ble_adv_fast_interval = APP_ADV_INTERVAL;
    init.config.ble_adv_fast_timeout  = APP_ADV_DURATION;

    init.evt_handler = on_adv_evt;

    err_code = ble_advertising_init(&m_advertising, &init);
    APP_ERROR_CHECK(err_code);

    ble_advertising_conn_cfg_tag_set(&m_advertising, APP_BLE_CONN_CFG_TAG);
}


/**@brief Function for initializing buttons and leds.
 *
 * @param[out] p_erase_bonds  Will be true if the clear bonding button was pressed to wake the application up.
 */
static void buttons_leds_init(bool * p_erase_bonds)
{
    ret_code_t err_code;
    bsp_event_t startup_event;

    err_code = bsp_init(BSP_INIT_LEDS | BSP_INIT_BUTTONS, bsp_event_handler);
    APP_ERROR_CHECK(err_code);

    err_code = bsp_btn_ble_init(NULL, &startup_event);
    APP_ERROR_CHECK(err_code);

    *p_erase_bonds = (startup_event == BSP_EVENT_CLEAR_BONDING_DATA);
}
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
int main(void)
{
    bool erase_bonds;

    // Initialize.
    log_init();
    timers_init();
    buttons_leds_init(&erase_bonds);
    power_management_init();
    ble_stack_init();
    gap_params_init();
    gatt_init();
    services_init();
    advertising_init();
    conn_params_init();
    peer_manager_init();

    // Start execution.
    NRF_LOG_INFO("Walter Started.");

    advertising_start(erase_bonds);
    adv_tx_power_set();
    timers_start();

    // Enter main loop.
    for (;;)
    {
        NRF_LOG_INFO("Sleeping...")
        idle_state_handle();
    }
}


/**
 * @}
 */

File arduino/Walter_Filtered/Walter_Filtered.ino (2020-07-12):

#include <CapacitiveSensor.h>

CapacitiveSensor   cs_4_2 = CapacitiveSensor(4,7);        // 10M resistor between pins 4 & 2, pin 2 is sensor pin, add a wire and or foil if desired

const long n = 10;
long buff[n];
long pos = 0;

void setup() {
   cs_4_2.set_CS_AutocaL_Millis(0xFFFFFFFF);     // turn off autocalibrate on channel 1 - just as an example
   Serial.begin(9600);
}

void loop() {
  long value = cs_4_2.capacitiveSensorRaw(30);
  Serial.println(moving_average_filter(value));                  // print sensor output 1
    
  delay(100);                             // arbitrary delay to limit data to serial port 
}

long moving_average_filter(long new_value) {
  buff[pos%n] = new_value;

  long sum = 0;

  for(int i = 0; i < n; i++) {
    sum += buff[i];
  }

  if (pos < n) pos++;
  else pos = 0;

  return(sum/n);
}

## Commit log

2020-07-12 fix continue and replce with pass
    [create_dataset.py]
2020-07-12 update arduino code
2020-07-12 remove print from moving average func
2020-07-12 arduino code for moving average
2020-07-14 images and circuit diagram
2020-07-14 add completion of moving average filter in TODO
2020-07-21 option to show graph without error range
    [statistics.py]
2020-07-22 voltage regulator datasheet added
2020-07-26 eagle schematics
    [walter.brd, walter.sch]
2020-07-30 remove eagle-cad
    [walter.brd, walter.sch]
2020-07-30 re-add eagle-cad
    [walter.brd, walter.sch]
2020-08-15 move arduino code to it's own folder
2020-09-15 schematics update
    [walter.brd, walter.sch]
2020-09-20 v2 regulator board
    [walter.brd, walter.sch]
2020-09-20 board routing layout fixes
    [walter.brd]
2021-07-13 integrate with sensor
2021-07-16 1. connected led off 2. fix notif data send
    [capsense.c, main.c]
2021-07-26 calibration mechanism done
2021-10-08 power mgmt init commit

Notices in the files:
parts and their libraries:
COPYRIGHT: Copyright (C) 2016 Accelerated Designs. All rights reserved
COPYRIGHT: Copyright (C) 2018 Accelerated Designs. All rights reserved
